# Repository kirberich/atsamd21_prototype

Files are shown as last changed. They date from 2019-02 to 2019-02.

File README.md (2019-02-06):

# ATSAMD21 Prototype board

This is a first prototype of a simple, debuggable, Arduino-Nano-ish development board. It's unlikely to be useful to anyone, it's just a proving ground for building more useful boards in future revisions once this one is shown to work.

For an actual development board, I'd recommend buying Adafruit's Feather M0 Express. The MCU package in this eagle file is taken from that board.

https://github.com/adafruit/Adafruit-Feather-M0-Express-PCB

https://www.adafruit.com/product/3403

In the UK: https://shop.pimoroni.com/products/adafruit-feather-m0-express-designed-for-circuitpython-atsamd21-cortex-m0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

Licensed under Creative Commons CC BY-SA 4.0: https://creativecommons.org/licenses/by-sa/4.0/

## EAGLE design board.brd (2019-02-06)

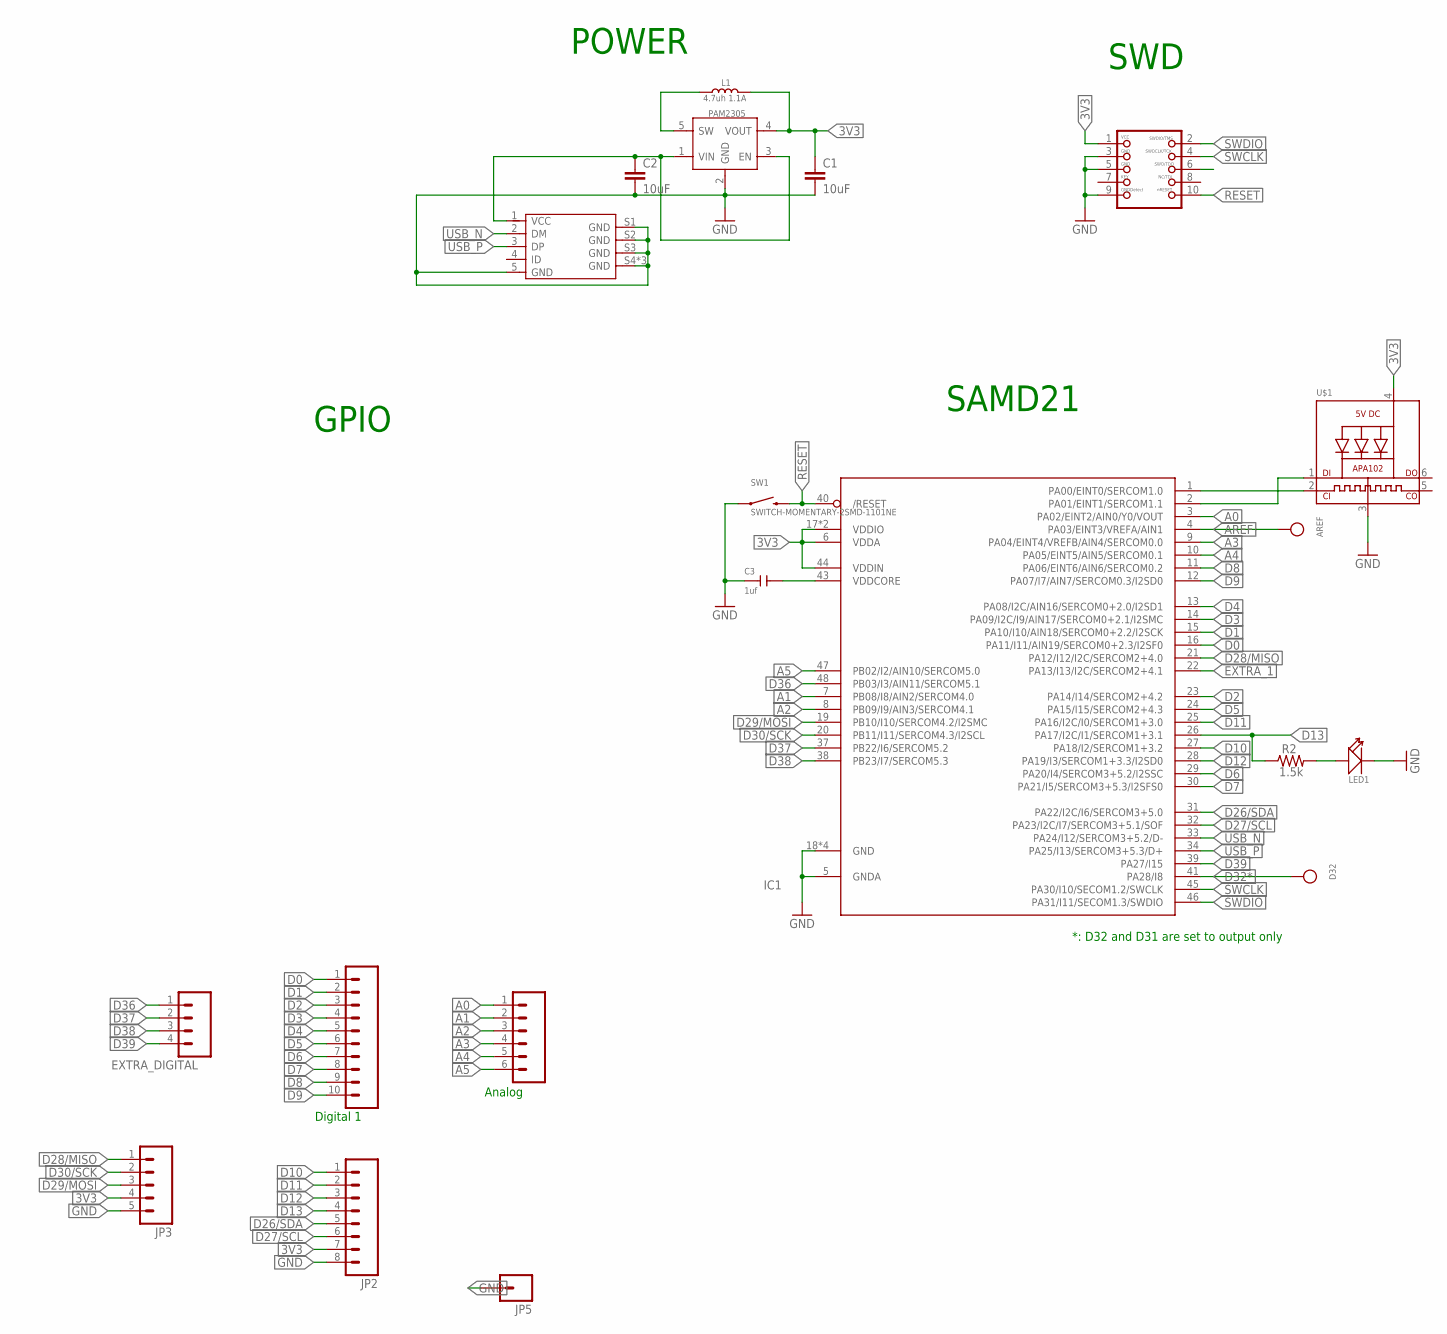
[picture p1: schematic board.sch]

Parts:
ANALOG: 6p-2.54; 1X06_NO_SILK
AREF: TESTPOINTROUND1MM; TESTPOINT_ROUND_1MM
C1, C2: 10uF; 0805
C3: 1uf; C0805
D32: TESTPOINTROUND1MM; TESTPOINT_ROUND_1MM
EXTRA_DIGITAL: M04NO_SILK_ALL_ROUND; 1X04_NO_SILK_ALL_ROUND
IC1: MICROBUILDER_ATSAMD21G_QFN; MICROBUILDER_TQFN48_7MM
JP1: M10NO_SILK_PTH_FEMALE; 1X10_NO_SILK
JP2: M08NO_SILK_FEMALE_PTH; 1X08_NO_SILK
JP3: M05NO_SILK; 1X05_NO_SILK
JP5: M01PTH_NO_SILK_YES_STOP; 1X01_NO_SILK
JTAG1: JTAG-CORTEXM3; 2X05_1.27MM_SMT
L1: 4.7uh 1.1A; L1008
LED1: RED-0805; LED-0805
PAM2305: XC6204B332MR-SOT23-5; SOT-23-5
R2: 1.5k; 0805
SW1: SWITCH-MOMENTARY-2SMD-1101NE; TACTILE-SWITCH-1101NE
U$1: MICROBUILDER_APA102
USB2: ST-USB-001G; MICRO-USB5+4P-SMD-0.65-B

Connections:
3V3: C1.1, IC1.6 (VDDA), IC1.17 (VDDIO), IC1.36 (VDDIO), IC1.44 (VDDIN), JP2.7, JP3.4, JTAG1.1, L1.2, PAM2305.4 (VOUT), U$1.4 (VDD)
A0: ANALOG.1, IC1.3 (PA02/EINT2/AIN0/Y0/VOUT)
A1: ANALOG.2, IC1.7 (PB08/I8/AIN2/SERCOM4.0)
A2: ANALOG.3, IC1.8 (PB09/I9/AIN3/SERCOM4.1)
A3: ANALOG.4, IC1.9 (PA04/EINT4/VREFB/AIN4/SERCOM0.0)
A4: ANALOG.5, IC1.10 (PA05/EINT5/AIN5/SERCOM0.1)
A5: ANALOG.6, IC1.47 (PB02/I2/AIN10/SERCOM5.0)
AREF: AREF.P$1, IC1.4 (PA03/EINT3/VREFA/AIN1)
D0: IC1.16 (PA11/I11/AIN19/SERCOM0+2.3/I2SF0), JP1.1
D1: IC1.15 (PA10/I10/AIN18/SERCOM0+2.2/I2SCK), JP1.2
D2: IC1.23 (PA14/I14/SERCOM2+4.2), JP1.3
D3: IC1.14 (PA09/I2C/I9/AIN17/SERCOM0+2.1/I2SMC), JP1.4
D4: IC1.13 (PA08/I2C/AIN16/SERCOM0+2.0/I2SD1), JP1.5
D5: IC1.24 (PA15/I15/SERCOM2+4.3), JP1.6
D6: IC1.29 (PA20/I4/SERCOM3+5.2/I2SSC), JP1.7
D7: IC1.30 (PA21/I5/SERCOM3+5.3/I2SFS0), JP1.8
D8: IC1.11 (PA06/EINT6/AIN6/SERCOM0.2), JP1.9
D9: IC1.12 (PA07/I7/AIN7/SERCOM0.3/I2SD0), JP1.10
D10: IC1.27 (PA18/I2/SERCOM1+3.2), JP2.1
D11: IC1.25 (PA16/I2C/I0/SERCOM1+3.0), JP2.2
D12: IC1.28 (PA19/I3/SERCOM1+3.3/I2SD0), JP2.3
D13: IC1.26 (PA17/I2C/I1/SERCOM1+3.1), JP2.4, R2.1
D26/SDA: IC1.31 (PA22/I2C/I6/SERCOM3+5.0), JP2.5
D27/SCL: IC1.32 (PA23/I2C/I7/SERCOM3+5.1/SOF), JP2.6
D28/MISO: IC1.21 (PA12/I12/I2C/SERCOM2+4.0), JP3.1
D29/MOSI: IC1.19 (PB10/I10/SERCOM4.2/I2SMC), JP3.3
D30/SCK: IC1.20 (PB11/I11/SERCOM4.3/I2SCL), JP3.2
D32*: D32.P$1, IC1.41 (PA28/I8)
D36: EXTRA_DIGITAL.1, IC1.48 (PB03/I3/AIN11/SERCOM5.1)
D37: EXTRA_DIGITAL.2, IC1.37 (PB22/I6/SERCOM5.2)
D38: EXTRA_DIGITAL.3, IC1.38 (PB23/I7/SERCOM5.3)
D39: EXTRA_DIGITAL.4, IC1.39 (PA27/I15)
D40: IC1.1 (PA00/EINT0/SERCOM1.0), U$1.2 (CKI)
D41: IC1.2 (PA01/EINT1/SERCOM1.1), U$1.1 (DI)
EXTRA_1: IC1.22 (PA13/I13/I2C/SERCOM2+4.1)
GND: C1.2, C2.2, C3.1, IC1.5 (GNDA), IC1.18 (GND), IC1.35 (GND), IC1.42 (GND), IC1.GND, JP2.8, JP3.5, JP5.1, JTAG1.3, JTAG1.5, JTAG1.9, LED1.-, PAM2305.2 (GND), SW1.1, U$1.3 (GND), USB2.5 (GND), USB2.S1 (GND), USB2.S2 (GND), USB2.S3 (GND), USB2.S4 (GND), USB2.S5 (GND), USB2.S6 (GND)
LED: LED1.+, R2.2
unnamed: L1.1, PAM2305.5 (SW)
unnamed: C3.2, IC1.43 (VDDCORE)
RESET: IC1.40 (/RESET), JTAG1.10, SW1.2
SWCLK: IC1.45 (PA30/I10/SECOM1.2/SWCLK), JTAG1.4
SWDIO: IC1.46 (PA31/I11/SECOM1.3/SWDIO), JTAG1.2
USB_N: IC1.33 (PA24/I12/SERCOM3+5.2/D-), USB2.2 (DM)
USB_P: IC1.34 (PA25/I13/SERCOM3+5.3/D+), USB2.3 (DP)
VBAT: C2.1, PAM2305.1 (VIN), PAM2305.3 (EN), USB2.1 (VCC)

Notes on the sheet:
POWER
*: D32 and D31 are set to output only
Analog
SWD
SAMD21
GPIO
Digital 1

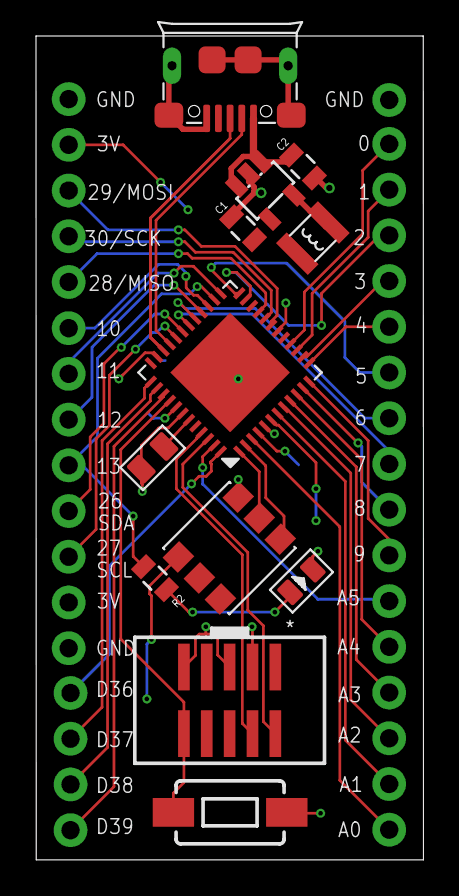
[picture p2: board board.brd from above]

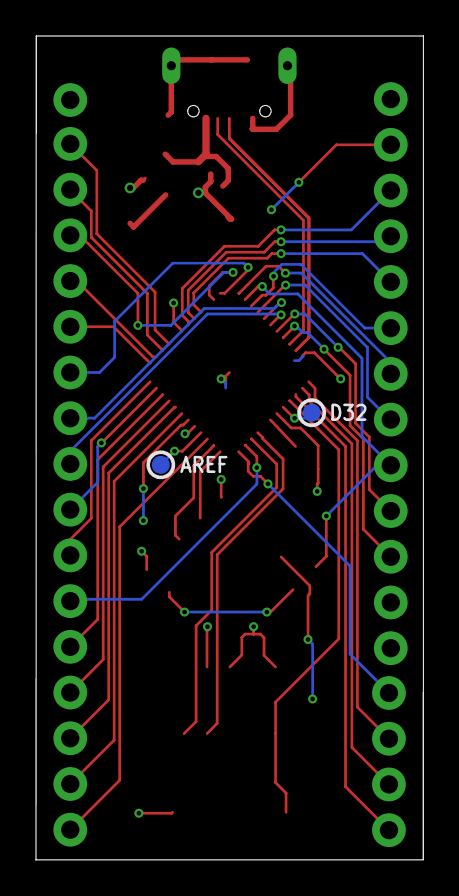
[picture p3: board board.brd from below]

Board: 2 copper layers, 21.5 x 45.8 mm, 20 parts (2 on the bottom side), 44 nets.

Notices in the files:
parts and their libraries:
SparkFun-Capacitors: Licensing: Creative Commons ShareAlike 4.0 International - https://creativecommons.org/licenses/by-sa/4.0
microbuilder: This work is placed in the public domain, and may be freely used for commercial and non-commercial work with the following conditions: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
